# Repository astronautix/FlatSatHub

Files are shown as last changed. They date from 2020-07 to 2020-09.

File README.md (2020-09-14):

# Introduction

This KiCAD project is part of the Astronautix FlatSat project, which aims to create an extensible platform for nanosatellite subsystem prototyping and experimentation.

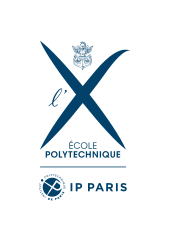
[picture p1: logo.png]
Polytechnique logo
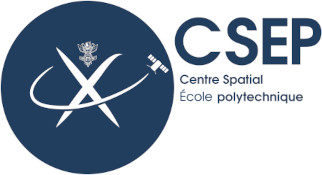
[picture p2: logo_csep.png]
CSEP logo
   

The FlatSat platform is composed of a main metallic support plate, which can possibly host 8 submodules in star configuration. Each submodule is composed of a STM32F429IDISCOVERY board and a custom adapter hat.

All modules are hooked to a central hub  (**this project**) via a sub-d DB26HD harness. The central hub has the main purpose of routing UART signals, regulating power (dispatched via sub-d, switchable) and linking all submodules together.

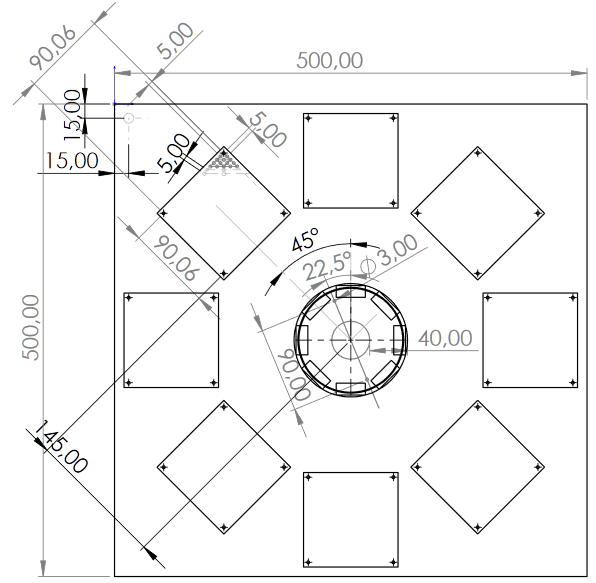
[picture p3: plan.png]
Board plan


# The IonSat FlatSat Hub

This is the repository to host the Flatsat central hub. 

The most important task of the FlatSat hub, aside of routing the module's signals together, is being able of handling and dispatching power. 
    
Compared to the modules, this results in a slightly more complex card layout, albeit prettier. 
The multi-level schematic also gets more intricate.

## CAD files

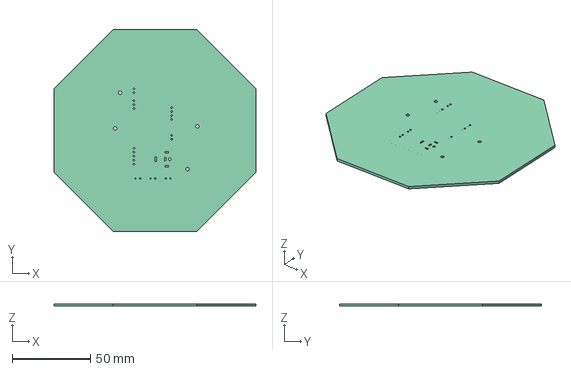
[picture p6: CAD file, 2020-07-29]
kicadStepUp.FCStd
129.3 x 129.3 x 1.60 mm

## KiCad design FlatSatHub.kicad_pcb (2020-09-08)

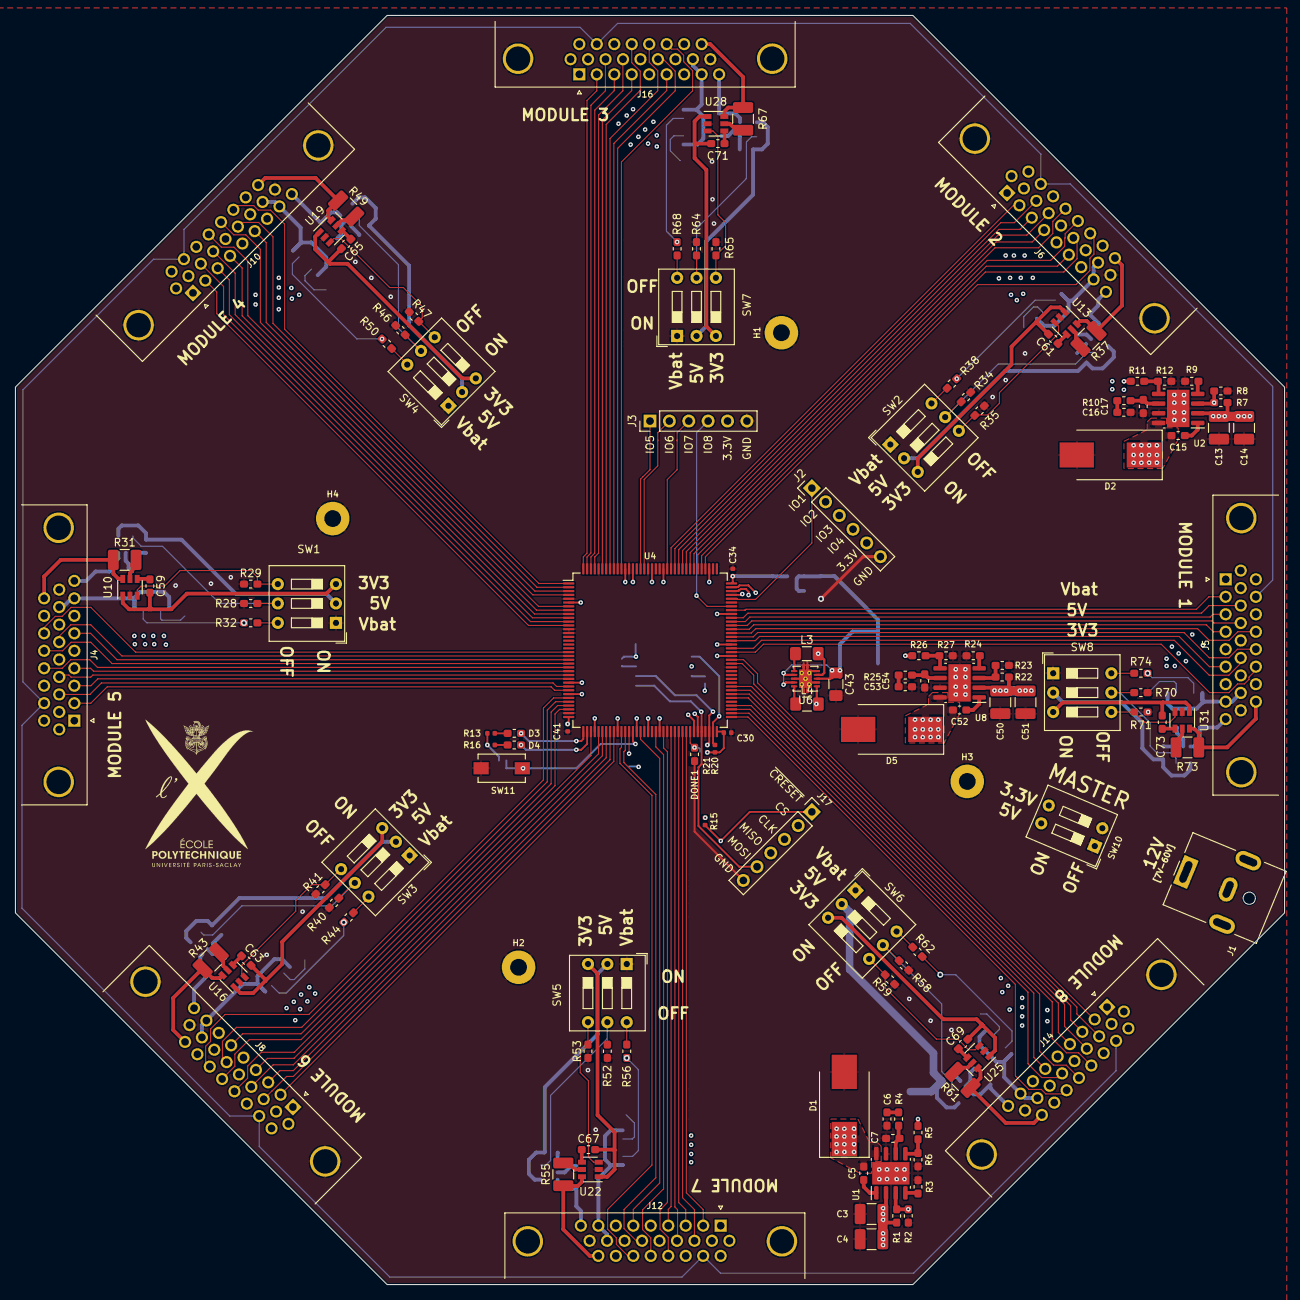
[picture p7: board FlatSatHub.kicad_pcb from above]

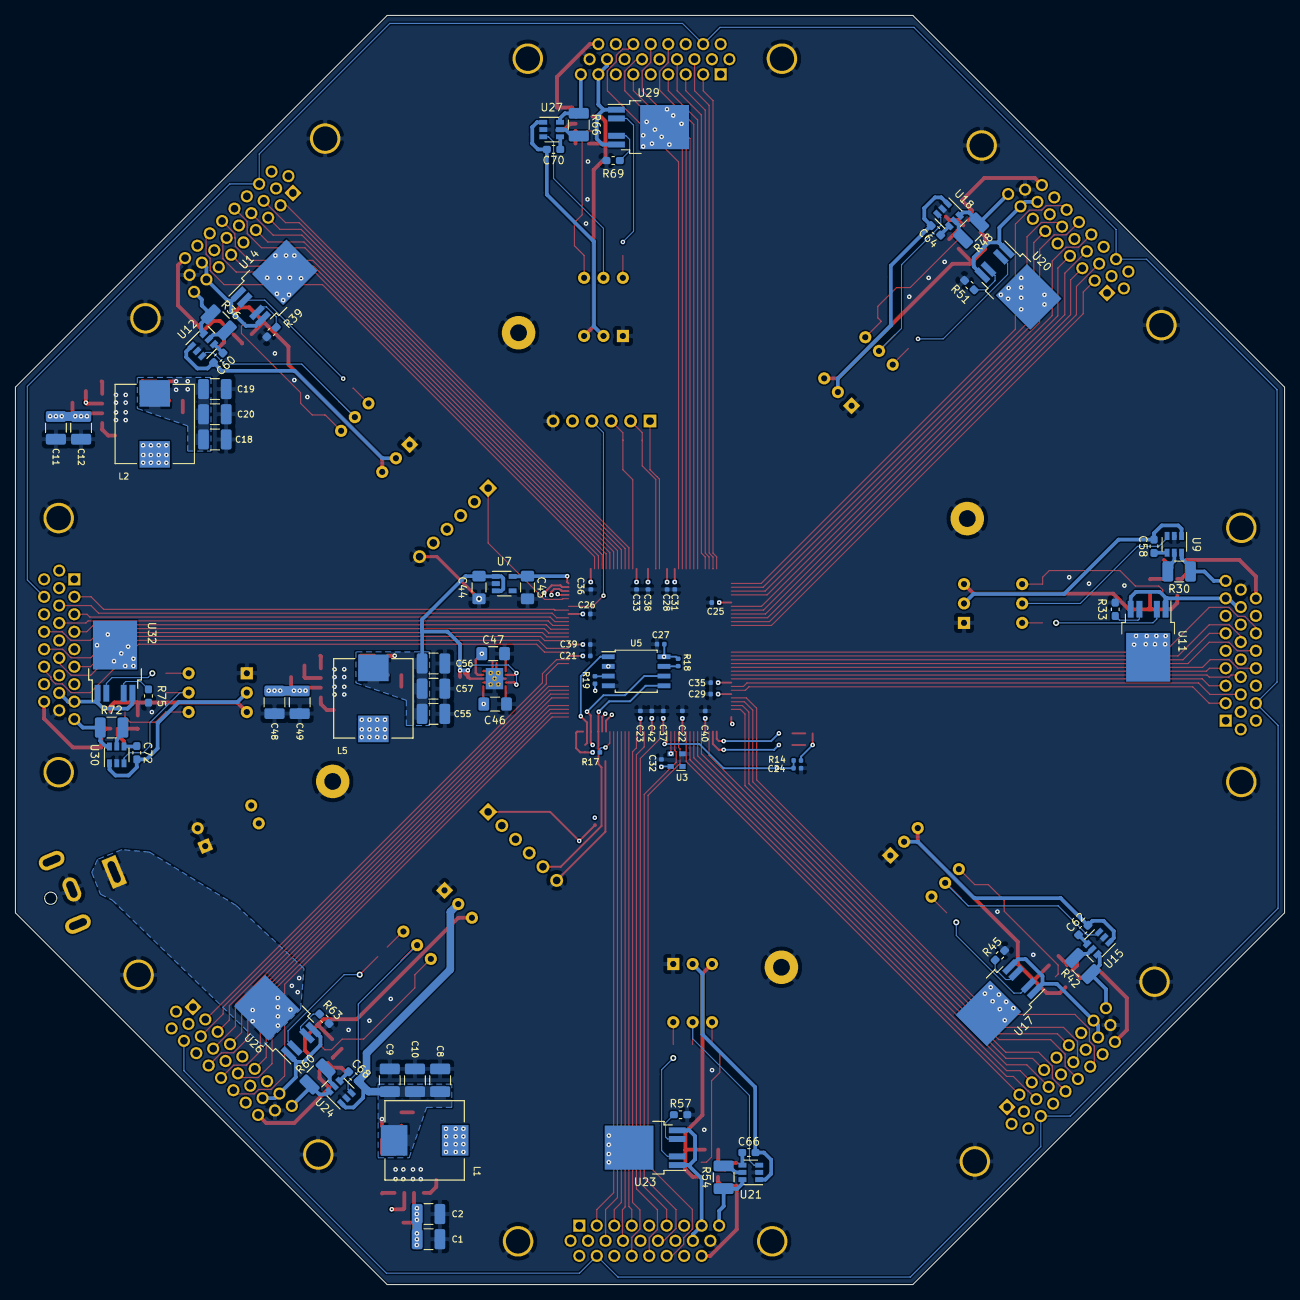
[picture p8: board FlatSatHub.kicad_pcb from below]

Board: 4 copper layers, 166.3 x 166.3 mm, 218 parts (88 on the bottom side), 237 nets.

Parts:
C1, C2, C3, C4, C11, C12, C13, C14, C48, C49, C50, C51: 2.2uF; C_1210_3225Metric_Pad1.42x2.65mm_HandSolder
C5, C6, C7, C15, C16, C17, C52, C53, C54, C58, C59, C60, C61, C62, C63, C64, C65, C66, C67, C68, C69, C70, C71, C72, C73: C; C_0603_1608Metric_Pad1.05x0.95mm_HandSolder
C8, C9, C10, C18, C19, C20, C55, C56, C57: 47u; C_1210_3225Metric_Pad1.42x2.65mm_HandSolder
C21, C22, C23, C24, C25, C26, C27, C28, C29, C30, C31, C32, C33, C34, C35, C36, C37, C38, C39, C40, C41, C42: 100nF; C_0402_1005Metric
C43, C44, C45, C46, C47: 10uF; C_1206_3216Metric_Pad1.42x1.75mm_HandSolder
D1, D2, D5: D_Schottky; D_SMC_Handsoldering
D3, D4: LED; R_0603_1608Metric_Pad1.05x0.95mm_HandSolder
DONE1: LED; R_0603_1608Metric_Pad1.05x0.95mm_HandSolder
H1, H2, H3, H4: MountingHole_Pad; MountingHole_2.2mm_M2_Pad
J1: Jack-DC; BarrelJack_CUI_PJ-063AH_Horizontal
J2, J3, J17: Conn_01x06; PinHeader_1x06_P2.54mm_Vertical
J4, J5, J6, J8, J10, J12, J14, J16: DB26_Male_HighDensity_MountingHoles; DSUB-26-HD_Female_Horizontal_P2.29x1.98mm_EdgePinOffset3.03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
L1, L2, L5: 7.2uH; L_Wuerth_HCI-1040
L3, L4: 2.2uH; L_1206_3216Metric_Pad1.42x1.75mm_HandSolder
LOGO1: LOGO; X-LOGO
R1, R2, R3, R4, R5, R6, R7, R8, R9, R10, R11, R12, R22, R23, R24, R25, R26, R27, R28, R29, R32, R33, R34, R35, R38, R39, R40, R41, R44, R45, R46, R47, R50, R51, R52, R53, R56, R57, R58, R59, R62, R63, R64, R65, R68, R69, R70, R71, R74, R75: R; R_0603_1608Metric_Pad1.05x0.95mm_HandSolder
R13, R14, R16, R17: 2K2; R_0402_1005Metric
R15, R18, R19, R20, R21: 10k; R_0402_1005Metric
R30, R31, R36, R37, R42, R43, R48, R49, R54, R55, R60, R61, R66, R67, R72, R73: R; R_1210_3225Metric_Pad1.42x2.65mm_HandSolder
SW1, SW2, SW3, SW4, SW5, SW6, SW7, SW8: SW_DIP_x03; SW_DIP_SPSTx03_Slide_9.78x9.8mm_W7.62mm_P2.54mm
SW10: SW_DIP_x02; SW_DIP_SPSTx02_Slide_9.78x7.26mm_W7.62mm_P2.54mm
SW11: SW_Push; SW_SPST_EVQPE1
U1, U2, U8: TPS54560B; Texas_R-PDSO-G8_EP2.95x4.9mm_Mask2.4x3.1mm
U3: ASDMB-xxxMHz; Oscillator_SMD_Abracon_ASDMB-4Pin_2.5x2.0mm
U4: ICE40HX1K-4K-TQ144; TQFP-144_20x20mm_P0.5mm
U5: M25PX32-VMW; SOIJ-8_5.3x5.3mm_P1.27mm
U6: tps6240x; Texas_S-PVSON-N10_ThermalVias
U7: TLV73325PDBV; SOT-23-5
U9, U10, U12, U13, U15, U16, U18, U19, U21, U22, U24, U25, U27, U28, U30, U31: TPS22917DBV; SOT-23-6
U11, U14, U17, U20, U23, U26, U29, U32: BTS6163D; TO-252-4

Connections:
/3.3V: C18.1, C19.1, C20.1, C59.2, C61.2, C63.2, C65.2, C67.2, C69.2, C71.2, C73.2, L2.2, R11.1, SW1.3, SW2.3, SW3.3, SW4.3, SW5.3, SW6.3, SW7.3, SW8.3, U10.1, U13.1, U16.1, U19.1, U22.1, U25.1, U28.1, U31.1
/5V: C8.1, C9.1, C10.1, C58.2, C60.2, C62.2, C64.2, C66.2, C68.2, C70.2, C72.2, L1.2, R5.1, SW1.2, SW2.2, SW3.2, SW4.2, SW5.2, SW6.2, SW7.2, SW8.2, U9.1, U12.1, U15.1, U18.1, U21.1, U24.1, U27.1, U30.1
/CAN1_RX: J4.14, J5.14, J6.14, J8.14, J10.14, J12.14, J14.14, J16.14
/CAN1_TX: J4.5, J5.5, J6.5, J8.5, J10.5, J12.5, J14.5, J16.5
/FPGA_2.5V: C34.1, C45.1, U4.108, U7.5
/I2C1_SCL: J4.19, J5.19, J6.19, J8.19, J10.19, J12.19, J14.19, J16.19
/I2C1_SDA: J4.10, J5.10, J6.10, J8.10, J10.10, J12.10, J14.10, J16.10
/I2C2_SCL: J4.20, J5.20, J6.20, J8.20, J10.20, J12.20, J14.20, J16.20
/I2C2_SDA: J4.1, J5.1, J6.1, J8.1, J10.1, J12.1, J14.1, J16.1
/MOD1_SPI1_MISO: J5.2, U4.101
/MOD1_SPI1_MOSI: J5.12, U4.99
/MOD1_SPI1_SS: J5.3, U4.98
/MOD1_SPI2_MISO: J5.13, U4.97
/MOD1_SPI2_MOSI: J5.22, U4.95
/MOD1_SPI2_SS: J5.4, U4.96
/MOD1_UART1_RX: J5.23, U4.94
/MOD1_UART1_TX: J5.15, U4.91
/MOD1_UART2_RX: J5.6, U4.93
/MOD1_UART2_TX: J5.24, U4.90
/MOD2_SPI1_MISO: J6.2, U4.121
/MOD2_SPI1_MOSI: J6.12, U4.120
/MOD2_SPI1_SS: J6.3, U4.119
/MOD2_SPI2_MISO: J6.13, U4.118
/MOD2_SPI2_MOSI: J6.22, U4.116
/MOD2_SPI2_SS: J6.4, U4.117
/MOD2_UART1_RX: J6.23, U4.115
/MOD2_UART1_TX: J6.15, U4.113
/MOD2_UART2_RX: J6.6, U4.114
/MOD2_UART2_TX: J6.24, U4.112
/MOD3_SPI1_MISO: J16.2, U4.144
/MOD3_SPI1_MOSI: J16.12, U4.143
/MOD3_SPI1_SS: J16.3, U4.142
/MOD3_SPI2_MISO: J16.13, U4.141
/MOD3_SPI2_MOSI: J16.22, U4.138
/MOD3_SPI2_SS: J16.4, U4.139
/MOD3_UART1_RX: J16.23, U4.137
/MOD3_UART1_TX: J16.15, U4.135
/MOD3_UART2_RX: J16.6, U4.136
/MOD3_UART2_TX: J16.24, U4.134
/MOD4_SPI1_MISO: J10.2, U4.12
/MOD4_SPI1_MOSI: J10.12, U4.11
/MOD4_SPI1_SS: J10.3, U4.10
/MOD4_SPI2_MISO: J10.13, U4.9
/MOD4_SPI2_MOSI: J10.22, U4.7
/MOD4_SPI2_SS: J10.4, U4.8
/MOD4_UART1_RX: J10.23, U4.4
/MOD4_UART1_TX: J10.15, U4.2
/MOD4_UART2_RX: J10.6, U4.3
/MOD4_UART2_TX: J10.24, U4.1
/MOD5_SPI1_MISO: J4.2, U4.29
/MOD5_SPI1_MOSI: J4.12, U4.28
/MOD5_SPI1_SS: J4.3, U4.26
/MOD5_SPI2_MISO: J4.13, U4.25
/MOD5_SPI2_MOSI: J4.22, U4.23
/MOD5_SPI2_SS: J4.4, U4.24
/MOD5_UART1_RX: J4.23, U4.22
/MOD5_UART1_TX: J4.15, U4.20
/MOD5_UART2_RX: J4.6, U4.21
/MOD5_UART2_TX: J4.24, U4.19
/MOD6_SPI1_MISO: J8.2, U4.45
/MOD6_SPI1_MOSI: J8.12, U4.44
/MOD6_SPI1_SS: J8.3, U4.43
/MOD6_SPI2_MISO: J8.13, U4.42
/MOD6_SPI2_MOSI: J8.22, U4.39
/MOD6_SPI2_SS: J8.4, U4.41
/MOD6_UART1_RX: J8.23, U4.34
/MOD6_UART1_TX: J8.15, U4.32
/MOD6_UART2_RX: J8.6, U4.33
/MOD6_UART2_TX: J8.24, U4.31
/MOD7_SPI1_MISO: J12.2, U4.64
/MOD7_SPI1_MOSI: J12.12, U4.63
/MOD7_SPI1_SS: J12.3, U4.62
/MOD7_SPI2_MISO: J12.13, U4.61
/MOD7_SPI2_MOSI: J12.22, U4.58
/MOD7_SPI2_SS: J12.4, U4.60
/MOD7_UART1_RX: J12.23, U4.56
/MOD7_UART1_TX: J12.15, U4.48
/MOD7_UART2_RX: J12.6, U4.52
/MOD7_UART2_TX: J12.24, U4.47
/MOD8_SPI1_MISO: J14.2, U4.88
/MOD8_SPI1_MOSI: J14.12, U4.87
/MOD8_SPI1_SS: J14.3, U4.81
/MOD8_SPI2_MISO: J14.13, U4.80
/MOD8_SPI2_MOSI: J14.22, U4.78
/MOD8_SPI2_SS: J14.4, U4.79
/MOD8_UART1_RX: J14.23, U4.76
/MOD8_UART1_TX: J14.15, U4.74
/MOD8_UART2_RX: J14.6, U4.75
/MOD8_UART2_TX: J14.24, U4.73
/SPI1_SCK: J4.11, J5.11, J6.11, J8.11, J10.11, J12.11, J14.11, J16.11
/SPI4_SCK: J4.21, J5.21, J6.21, J8.21, J10.21, J12.21, J14.21, J16.21
/Sheet5F4EF57F/Sheet5F4EF936/EN: R1.2, R2.1, SW10.4, U1.3
/Sheet5F4EF57F/Sheet5F698D24/5V: C43.1, C44.1, C55.1, C56.1, C57.1, L5.2, R26.1, U6.3, U6.7, U6.9, U7.1, U7.3
/Sheet5F4EF57F/sheet5F54C416/EN: R7.2, R8.1, SW10.3, U2.3
/Sheet5F4EF57F/sheet5F69D9D1/EN: R22.2, R23.1, U8.3
/Sheet5F604EE5/BP: C24.1, R14.2, SW11.2, U4.50
/Sheet5F604EE5/FLASH_CLK: J17.3, R21.2, U4.70, U5.6
/Sheet5F604EE5/FLASH_CS: J17.2, R20.2, U4.71, U5.1
/Sheet5F604EE5/FLASH_MISO: J17.4, U4.67, U5.2
/Sheet5F604EE5/FLASH_MOSI: J17.5, U4.68, U5.5
/Sheet5F604EE5/FLASH_~CRESET: J17.1, R15.2, U4.66
/Sheet5F604EE5/FPGA_CLK: U3.3, U4.49
/Sheet5F604EE5/IO1: J2.1, U4.104
/Sheet5F604EE5/IO2: J2.2, U4.105
/Sheet5F604EE5/IO3: J2.3, U4.106
/Sheet5F604EE5/IO4: J2.4, U4.107
/Sheet5F604EE5/IO5: J3.1, U4.129
/Sheet5F604EE5/IO6: J3.2, U4.128
/Sheet5F604EE5/IO7: J3.3, U4.122
/Sheet5F604EE5/IO8: J3.4, U4.102
/Sheet5F604EE5/LED1: D3.1, U4.37
/Sheet5F604EE5/LED2: D4.1, U4.38
/VBAT: C1.1, C2.1, C3.1, C4.1, C11.1, C12.1, C13.1, C14.1, C48.1, C49.1, C50.1, C51.1, J1.1, R1.1, R7.1, R22.1, U1.2, U2.2, U8.2, U11.3, U14.3, U17.3, U20.3, U23.3, U26.3, U29.3, U32.3
/sheet5F22A1B0/3.3V_SW: R29.2, SW1.4, U10.3
/sheet5F22A1B0/5V_SW: R28.2, SW1.5, U9.3
/sheet5F22A1B0/VBAT_SW: R32.2, SW1.6
/sheet5F22A1B0/bus_3v3: J4.26, R31.1, U10.6
/sheet5F22A1B0/bus_5v: J4.9, R30.1, U9.6
/sheet5F22A1B0/bus_vbat: J4.8, J4.17, U11.1, U11.5
/sheet5F22D1E8/3.3V_SW: R35.2, SW2.4, U13.3
/sheet5F22D1E8/5V_SW: R34.2, SW2.5, U12.3
/sheet5F22D1E8/VBAT_SW: R38.2, SW2.6
/sheet5F22D1E8/bus_3v3: J6.26, R37.1, U13.6
/sheet5F22D1E8/bus_5v: J6.9, R36.1, U12.6
/sheet5F22D1E8/bus_vbat: J6.8, J6.17, U14.1, U14.5
/sheet5F22D1E9/3.3V_SW: R41.2, SW3.4, U16.3
/sheet5F22D1E9/5V_SW: R40.2, SW3.5, U15.3
/sheet5F22D1E9/VBAT_SW: R44.2, SW3.6
/sheet5F22D1E9/bus_3v3: J8.26, R43.1, U16.6
/sheet5F22D1E9/bus_5v: J8.9, R42.1, U15.6
/sheet5F22D1E9/bus_vbat: J8.8, J8.17, U17.1, U17.5
/sheet5F66A269/3.3V_SW: R71.2, SW8.4, U31.3
/sheet5F66A269/5V_SW: R70.2, SW8.5, U30.3
/sheet5F66A269/VBAT_SW: R74.2, SW8.6
/sheet5F66A269/bus_3v3: J5.26, R73.1, U31.6
/sheet5F66A269/bus_5v: J5.9, R72.1, U30.6
/sheet5F66A269/bus_vbat: J5.8, J5.17, U32.1, U32.5
/sheet5F237BCE/3.3V_SW: R59.2, SW6.4, U25.3
/sheet5F237BCE/5V_SW: R58.2, SW6.5, U24.3
/sheet5F237BCE/VBAT_SW: R62.2, SW6.6
/sheet5F237BCE/bus_3v3: J14.26, R61.1, U25.6
/sheet5F237BCE/bus_5v: J14.9, R60.1, U24.6
/sheet5F237BCE/bus_vbat: J14.8, J14.17, U26.1, U26.5
/sheet5F237BCF/3.3V_SW: R65.2, SW7.4, U28.3
/sheet5F237BCF/5V_SW: R64.2, SW7.5, U27.3
/sheet5F237BCF/VBAT_SW: R68.2, SW7.6
/sheet5F237BCF/bus_3v3: J16.26, R67.1, U28.6
/sheet5F237BCF/bus_5v: J16.9, R66.1, U27.6
/sheet5F237BCF/bus_vbat: J16.8, J16.17, U29.1, U29.5
/sheet5F23178F/3.3V_SW: R47.2, SW4.4, U19.3
/sheet5F23178F/5V_SW: R46.2, SW4.5, U18.3
/sheet5F23178F/VBAT_SW: R50.2, SW4.6
/sheet5F23178F/bus_3v3: J10.26, R49.1, U19.6
/sheet5F23178F/bus_5v: J10.9, R48.1, U18.6
/sheet5F23178F/bus_vbat: J10.8, J10.17, U20.1, U20.5
/sheet5F231790/3.3V_SW: R53.2, SW5.4, U22.3
/sheet5F231790/5V_SW: R52.2, SW5.5, U21.3
/sheet5F231790/VBAT_SW: R56.2, SW5.6
/sheet5F231790/bus_3v3: J12.26, R55.1, U22.6
/sheet5F231790/bus_5v: J12.9, R54.1, U21.6
/sheet5F231790/bus_vbat: J12.8, J12.17, U23.1, U23.5
GND: C1.2, C2.2, C3.2, C4.2, C6.1, C7.1, C8.2, C9.2, C10.2, C11.2, C12.2, C13.2, C14.2, C16.1, C17.1, C18.2, C19.2, C20.2, C21.2, C22.2, C23.2, C24.2, C25.2, C26.2, C27.2, C28.2, C29.2, C30.2, C31.2, C32.2, C33.2, C34.2, C35.2, C36.2, C37.2, C38.2, C39.2, C40.2, C41.2, C42.2, C43.2, C44.2, C45.2, C46.2, C47.2, C48.2, C49.2, C50.2, C51.2, C53.1, C54.1, C55.2, C56.2, C57.2, D1.2, D2.2, D5.2, DONE1.1, H1.1, H2.1, H3.1, H4.1, J1.2, J2.6, J3.6, J4.0, J4.18, J5.0, J5.18, J6.0, J6.18, J8.0, J8.18, J10.0, J10.18, J12.0, J12.18, J14.0, J14.18, J16.0, J16.18, J17.6, R2.2, R3.2, R6.2, R8.2, R9.2, R12.2, R23.2, R24.2, R27.2, R28.1, R29.1, R33.1, R34.1, R35.1, R39.1, R40.1, R41.1, R45.1, R46.1, R47.1, R51.1, R52.1, R53.1, R57.1, R58.1, R59.1, R63.1, R64.1, R65.1, R69.1, R70.1, R71.1, R75.1, SW1.1, SW2.1, SW3.1, SW4.1, SW5.1, SW6.1, SW7.1, SW8.1, SW10.1, SW10.2, SW11.1, U1.7, U1.9, U2.7, U2.9, U3.2, U4.5, U4.13, U4.14, U4.35, U4.53, U4.59, U4.69, U4.86, U4.103, U4.127, U4.132, U4.140, U5.4, U6.2, U6.5, U6.8, U6.11, U7.2, U8.7, U8.9, U9.2, U10.2, U12.2, U13.2, U15.2, U16.2, U18.2, U19.2, U21.2, U22.2, U24.2, U25.2, U27.2, U28.2, U30.2, U31.2
unnamed: C5.1, D1.1, L1.1, U1.8
unnamed: C5.2, U1.1
unnamed: C6.2, R4.2
unnamed: C7.2, R4.1, U1.6
unnamed: C15.1, D2.1, L2.1, U2.8
unnamed: C15.2, U2.1
unnamed: C16.2, R10.2
unnamed: C17.2, R10.1, U2.6
unnamed: C52.1, D5.1, L5.1, U8.8
unnamed: C52.2, U8.1
unnamed: C53.2, R25.2
unnamed: C54.2, R25.1, U8.6
unnamed: C58.1, U9.4
unnamed: C59.1, U10.4
unnamed: C60.1, U12.4
unnamed: C61.1, U13.4
unnamed: C62.1, U15.4
unnamed: C63.1, U16.4
unnamed: C64.1, U18.4
unnamed: C65.1, U19.4
unnamed: C66.1, U21.4
unnamed: C67.1, U22.4
unnamed: C68.1, U24.4
unnamed: C69.1, U25.4
unnamed: C70.1, U27.4
unnamed: C71.1, U28.4
unnamed: C72.1, U30.4
unnamed: C73.1, U31.4
unnamed: D3.2, R13.2
unnamed: D4.2, R16.2
unnamed: DONE1.2, R17.2, U4.65
unnamed: L3.1, U6.6
unnamed: L4.1, U6.10
unnamed: R3.1, U1.4
unnamed: R5.2, R6.1, U1.5
unnamed: R9.1, U2.4
unnamed: R11.2, R12.1, U2.5
unnamed: R18.2, U5.7
unnamed: R19.2, U5.3
unnamed: R24.1, U8.4
unnamed: R26.2, R27.1, U8.5
unnamed: R30.2, U9.5
unnamed: R31.2, U10.5
unnamed: R32.1, U11.2
unnamed: R33.2, U11.4
unnamed: R36.2, U12.5
unnamed: R37.2, U13.5
unnamed: R38.1, U14.2
unnamed: R39.2, U14.4
unnamed: R42.2, U15.5
unnamed: R43.2, U16.5
unnamed: R44.1, U17.2
unnamed: R45.2, U17.4
unnamed: R48.2, U18.5
unnamed: R49.2, U19.5
unnamed: R50.1, U20.2
unnamed: R51.2, U20.4
unnamed: R54.2, U21.5
unnamed: R55.2, U22.5
unnamed: R56.1, U23.2
unnamed: R57.2, U23.4
unnamed: R60.2, U24.5
unnamed: R61.2, U25.5
unnamed: R62.1, U26.2
unnamed: R63.2, U26.4
unnamed: R66.2, U27.5
unnamed: R67.2, U28.5
unnamed: R68.1, U29.2
unnamed: R69.2, U29.4
unnamed: R72.2, U30.5
unnamed: R73.2, U31.5
unnamed: R74.1, U32.2
unnamed: R75.2, U32.4
VCC: C35.1, C36.1, C37.1, C38.1, C39.1, C40.1, C41.1, C42.1, C47.1, L3.2, U4.27, U4.36, U4.40, U4.51, U4.54, U4.92, U4.111, U4.126, U6.4
VCCIO_0: C21.1, C22.1, C23.1, C25.1, C26.1, C27.1, C28.1, C29.1, C30.1, C31.1, C32.1, C33.1, C46.1, J2.5, J3.5, L4.2, R13.1, R14.1, R15.1, R16.1, R17.1, R18.1, R19.1, R20.1, R21.1, U3.4, U4.6, U4.30, U4.46, U4.57, U4.72, U4.89, U4.100, U4.123, U4.131, U4.133, U5.8, U6.1

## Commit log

2020-07-10 create cutout
    [FlatSatHub.kicad_pcb, FlatSatHub.sch, connector.sch]
2020-07-16 schematic improvements
    [FlatSatHub.sch, connector.sch]
2020-07-16 add power management wiring and mounting holes
    [FlatSatHub.sch, connector.sch, file5F10DACD.sch]
2020-07-16 create footprints
    [FlatSatHub.kicad_pcb, FlatSatHub.sch, connector.sch]
2020-07-16 First placement and autorouting
    [FlatSatHub.kicad_pcb, FlatSatHub.sch]
2020-07-28 rework power management schematic
    [FlatSatHub.kicad_pcb, FlatSatHub.sch, connector.sch]
2020-07-29 try improving positionning
    [FlatSatHub.kicad_pcb, FlatSatHub.sch, connector.sch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]
2020-07-29 re-place footprints for symmetry
    [FlatSatHub.kicad_pcb]
2020-07-29 minor improvements
    [FlatSatHub.kicad_pcb, FlatSatHub.sch, connector.sch]
2020-07-31 route and add documentation for schematic
    [FlatSatHub.kicad_pcb, FlatSatHub.sch, connector.sch]
2020-07-31 add markings for switchs
    [FlatSatHub.kicad_pcb]
2020-08-03 Change DB-26-HD footprint to match what we want
    [FlatSatHub.kicad_pcb, FlatSatHub.sch, connector.sch]
2020-08-04 Rewire with new footprints
    [FlatSatHub.kicad_pcb]
2020-08-04 fix wiring and add serigraphy
    [FlatSatHub.kicad_pcb]
2020-08-05 new UART layout and rewire
    [FlatSatHub.kicad_pcb, FlatSatHub.sch, obc.sch]
2020-08-06 add silkscreen for uarts
    [FlatSatHub.kicad_pcb]
2020-08-06 fix dc converter wiring and gnd track size
    [FlatSatHub.kicad_pcb, FlatSatHub.sch]
2020-08-06 moved vias out of the way of writings
    [FlatSatHub.kicad_pcb]
2020-09-01 Switch to female footprints and update positionning
    [FlatSatHub.kicad_pcb, connector.sch, obc.sch]
2020-09-08 V1.0 (#1)
    * New layout with FPGA
    - Added FPGA to ease UART and SPI signals routing
    - Cleaned layout using start and circle patterns for remaining signals
    - Replaced DCDC modules with better TI components
    Missing stuff:
    - per module PSU switch
    - spare FPGA IOs connector?
    - silk screen
    - ...
    * Most PSB done, needs more silk screen cosmetic plus review
    * added some text, moved headers, added X logo, fixed res/diode overlap, fixed DRC
    * Last few silk screen cleanups
    Co-authored-by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
    [FPGA.sch, FPGA_power.sch, FlatSatHub.kicad_pcb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]

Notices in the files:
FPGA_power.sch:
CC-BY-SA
